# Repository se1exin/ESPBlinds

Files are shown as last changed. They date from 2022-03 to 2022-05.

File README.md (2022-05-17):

# ESPBlinds - Wifi Controlled Roller Blinds

STLs are available in the [files](files) folder in this repo, and on thingiverse at: https://www.thingiverse.com/thing:5321952

## Arduino Program
This Repo contains the Arduino program used to run the ESP-8266 controller.

The code has been tested on Arduino IDE v1.8.19 on Linux and Mac, if you have issues compiling please try using this version of the Arduino IDE.

### Constants file
**IMPORTANT: You need to create constants.h**

Copy-paste the file `constants.example.h` to `constants.h` and fill update at minimum the following variables:
 - `WIFI_SSID`
 - `WIFI_PASSWORD`
 - `MQTT_SERVER`
 - `MQTT_USER`
 - `MQTT_PASSWORD`

All MQTT topics are also defined in `constants.h`, feel free to customise these if you prefer different topic naming.

### Arduino Libraries 
Please ensure the following Arduino Libraries are installed using the Arduino Library Manager:
 - ESP8266WiFi - https://arduino-esp8266.readthedocs.io/en/latest/esp8266wifi/readme.html
 - PubSubClient -  https://www.arduino.cc/reference/en/libraries/pubsubclient/

### Compiling for ESP8266
If you are using the ESP-12F modukle as I did, use the following Board settings in Arduino IDE:
- Board: `NodeMCU 1.0 (ESP-12E)`
- Upload Speed: `115200`
- (I left all other settings as the default)

## Parts used
 - 2.8v 1.7A Stepper Driver (SY42STH38-1684A): https://www.pololu.com/product/2267
 - DRV8825 Stepper Motor Driver: https://www.pololu.com/product/2133
 - ESP8266 12-F: https://www.katranji.com/tocimages/files/423280-229082.pdf
 - 12v DC 50mm Fan: https://core-electronics.com.au/extruder-50mm-fan.html
 - 12v 2A DC Power Supply (no link - just make sure the amperage is higher than your stepper, with some room to breath to also run the ESP8266)
 - 4x8x3mm Bearings for the main gear - https://core-electronics.com.au/makeblock-plain-ball-bearing-4-8-3mm-10-pack.html
 - M3x8mm screws (x4) for mounting the motor
 - M3x4mm screws (x4) for mounting the lid
 - 4x wood screws to mount the whole thing to the wall - you will need to decide the best screws to use based on what your wall is made out of.

...and some generic electronics components, such as 3.3v regulator, capacitors, resistors, and NPN transistors.

See the schematic for full details

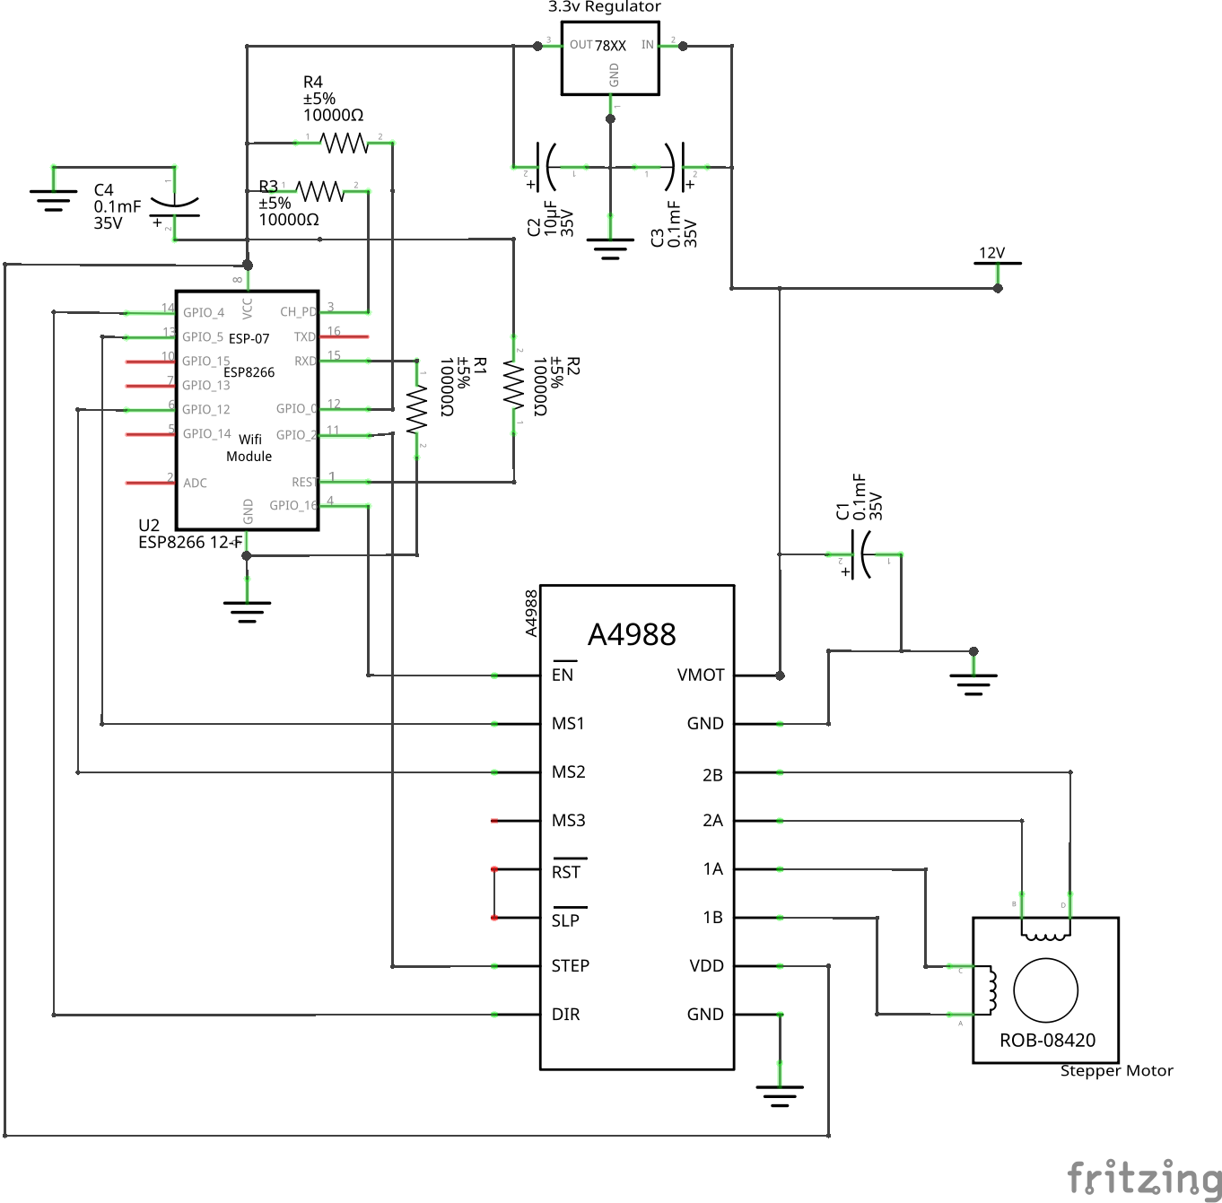
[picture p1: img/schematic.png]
Schematic


**NOTE** The schematic shows the A4988 Stepper Driver, which was from a previous iteration. I am now using the DRV8255 which has a slightly different pinout.

Most notably on the DRV8255, the VDD pin is not present and instead replaced by the FAULT pin (which I am not using), and the RST and SLP pins go to 3.3v rather than being tied to each other.

## Mounting instructions
- First mount the enclosure to the wall. The motor covers one of the screw holes.
- Mount the stepper motor before adding the main gear - it covers access to 2 of the motor screw holes
- Then put in the main gear and everything else
- Then add on the lid!

## MQTT Topics
The unit is controlled remotely via MQTT, as I use Home Assistant and the MQTT integration for all my home automation projects.

See `constants.example.h` for all the available topics - you can also change the topic stings to whatever you want.

The topics are grouped into two types: Control and Non-Control topics. Control topics have `control` somewhere in the name, and the unit listens to these topics and does something (e.g. moves the blinds) when a message is received on the topic. Non-control topics don't have the word `control` in the them, and are used to send messages out from the unit to let the world know it's current states and settings.

### Control Topics

#### `MQTT_TOPIC_CONTROL_ENABLED`
Enables/Disables the Stepper Motor Driver - useful for emergency stopping the motor

Expected Values:
 - `0` - Disable
 - `1` - Enable

#### `MQTT_TOPIC_CONTROL_DIRECTION`
Changes the direction of the stepper motor/the direction the blinds will move

Expected Values:
 - `0` - Open/Up
 - `1` - Close/Down

#### `MQTT_TOPIC_CONTROL_STEPFOR`
Immediately move the stepper motor X *full* steps, in the currently set direction (e.g. set via `MQTT_TOPIC_CONTROL_DIRECTION`).

Expected Value: An integer for the number of steps

#### `MQTT_TOPIC_CONTROL_BLINDS`
Tell the blinds to either open or close, for the set number of steps required to complete the journey (e.g. set via `MQTT_TOPIC_CONTROL_STEPS_VERTICAL`)

Expected Values:
 - `opened` - Open the blinds
 - `closed` - Close the blinds

#### `MQTT_TOPIC_CONTROL_MODE_OPEN`
Set the stepper mode used during *Opening* of Blinds (e.g. full step, half step, quarter step, etc)

**This value is saved to eeprom, so it will persist if the ESP8266 restarts or looses power**

Expected Values:
 - `1` - Full Step Mode
 - `2` - Half Step Mode
 - `4` - Quarter Step Mode
 - `8` - Eighth Step Mode

#### `MQTT_TOPIC_CONTROL_MODE_CLOSE`
Set the stepper mode used during *Closing* of Blinds (e.g. full step, half step, quarter step, etc)

**This value is saved to eeprom, so it will persist if the ESP8266 restarts or looses power**

Expected Values:
 - `1` - Full Step Mode
 - `2` - Half Step Mode
 - `4` - Quarter Step Mode
 - `8` - Eighth Step Mode

#### `MQTT_TOPIC_CONTROL_DELAY_OPEN`
Set the stepper speed used during *Opening* of Blinds. (Less speed == more torque).

**This value is saved to eeprom, so it will persist if the ESP8266 restarts or looses power**

Expected Value: An integer for the **microseconds** between steps

#### `MQTT_TOPIC_CONTROL_DELAY_CLOSE`
Set the stepper speed used during *Closing* of Blinds. (Less speed == more torque).

**This value is saved to eeprom, so it will persist if the ESP8266 restarts or looses power**

Expected Value: An integer for the **microseconds** between steps

#### `MQTT_TOPIC_CONTROL_STEPS_VERTICAL`
Set the number of steps to take when performing a full `open` or `close` cycle (See `MQTT_TOPIC_CONTROL_BLINDS`)

**This value is saved to eeprom, so it will persist if the ESP8266 restarts or looses power**

Expected Value: An integer for the number of steps to take

## Non-Control Topics

#### `MQTT_TOPIC_STATE`
Publishes the current movement state of the blinds

Expected Values:
 - `opening`
 - `opened`
 - `closing`
 - `closed`

#### `MQTT_TOPIC_STATE`
Publishes the current movement state of the blinds

Expected Values:
 - `opening`
 - `opened`
 - `closing`
 - `closed`

#### `MQTT_TOPIC_STEPS`
Publishes the current number of full steps taken (note this is only sent every 250 steps)

Expected Value: Integer

#### `MQTT_TOPIC_ENABLED`
Publishes if the stepper motor driver is currently enabled

Expected Values:
 - `0` - Not Enabled
 - `1` - Enabled

#### `MQTT_TOPIC_DIRECTION`
Publishes the current stepper motor direction

Expected Values:
 - `forwards`
 - `backwards`

#### `MQTT_TOPIC_MODE`
Publishes the current stepper motor step mode

Expected Values:
 - `1` - Full Step Mode
 - `2` - Half Step Mode
 - `4` - Quarter Step Mode
 - `8` - Eighth Step Mode

#### `MQTT_TOPIC_STATUS`
Publishes the current MQTT connection status

Expected Values:
 - `connected` - The unit is connected to MQTT
 - `disconnected` - The unit has disconnected from MQTT (this is sent as an MQTT last-will message, so it is mostly reliable)

#### `MQTT_TOPIC_MODE_OPEN`
Publishes the current step mode for the *Opening* sequence (see `MQTT_TOPIC_CONTROL_MODE_OPEN`)

Expected Values:
 - `1` - Full Step Mode
 - `2` - Half Step Mode
 - `4` - Quarter Step Mode
 - `8` - Eighth Step Mode

#### `MQTT_TOPIC_MODE_CLOSE`
Publishes the current step mode setting for the *Closing* sequence (see `MQTT_TOPIC_CONTROL_MODE_CLOSE`)

Expected Values:
 - `1` - Full Step Mode
 - `2` - Half Step Mode
 - `4` - Quarter Step Mode
 - `8` - Eighth Step Mode

#### `MQTT_TOPIC_DELAY_OPEN`
Publishes the current step speed setting for the *Opening* sequence (see `MQTT_TOPIC_CONTROL_DELAY_OPEN`)

Expected Value: Integer

#### `MQTT_TOPIC_DELAY_CLOSE`
Publishes the current step speed setting for the *Closing* sequence (see `MQTT_TOPIC_CONTROL_DELAY_CLOSE`)

Expected Value: Integer

#### `MQTT_TOPIC_STEPS_VERTICAL`
Publishes the setting for the current number of full steps to take when performing a full `open` or `close` cycle (see `MQTT_TOPIC_CONTROL_STEPS_VERTICAL`)

Expected Value: Integer

## Some more pics

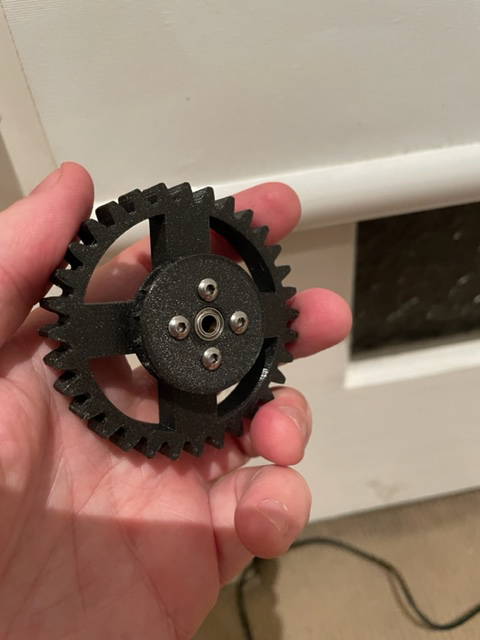
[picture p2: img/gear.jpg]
Gear


Main gear with ball-chain gear attachment

---

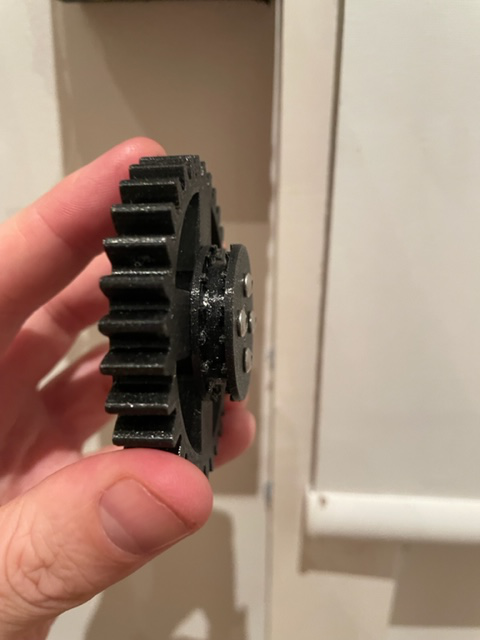
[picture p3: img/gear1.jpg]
Ball-Chain attachment


Ball-chain gear attachment (another angle)

---

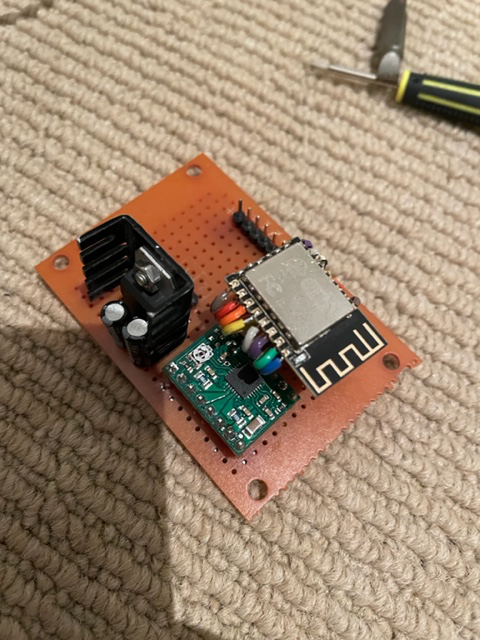
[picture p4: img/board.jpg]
Control Board


Control Board (with A4988 instead of DRV8255 stepper driver)

---

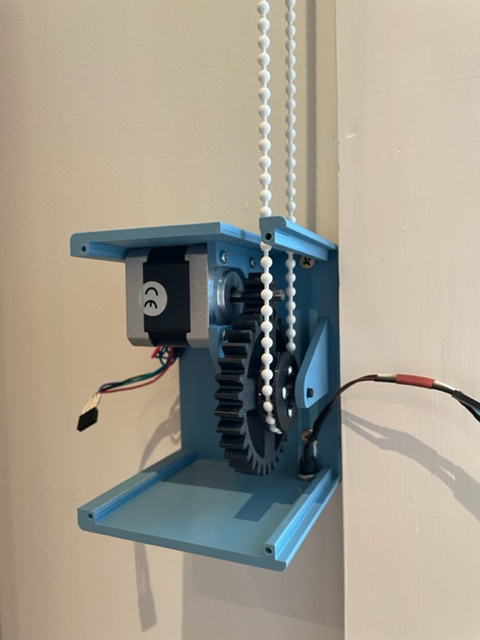
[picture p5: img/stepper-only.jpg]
Housing with stepper


Housing with stepper motor and gear installed

---

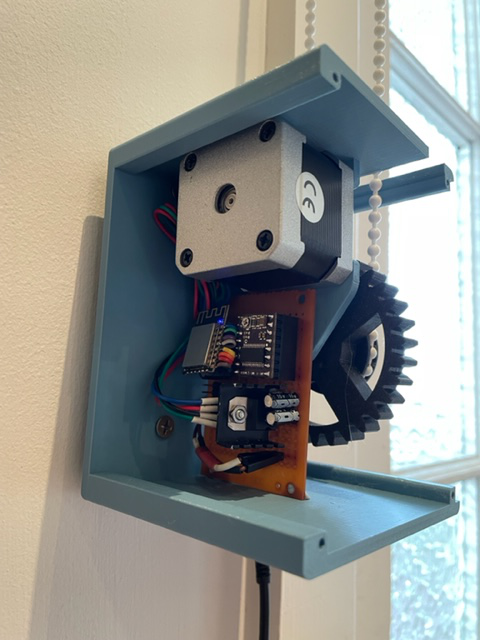
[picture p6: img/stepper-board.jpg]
Housing with stepper and board


Housing with stepper motorm, gears, and board installed

---

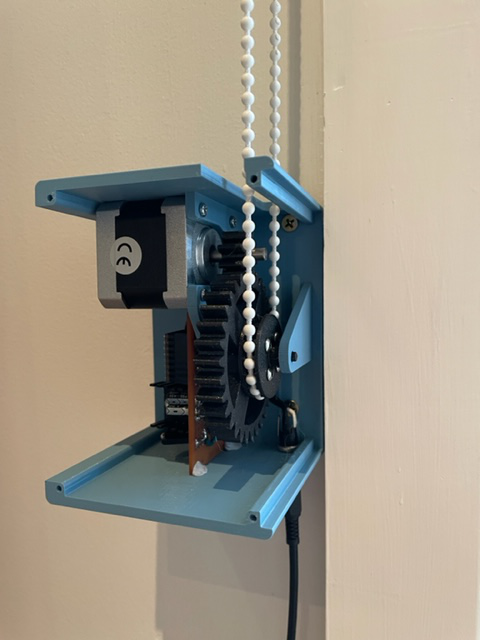
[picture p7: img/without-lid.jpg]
Housing with stepper and board


Everything ready to go, just need to put the lid on

## License
MIT - see [LICENSE.md](https://github.com/se1exin/ESPBlinds/blob/master/LICENSE.md)

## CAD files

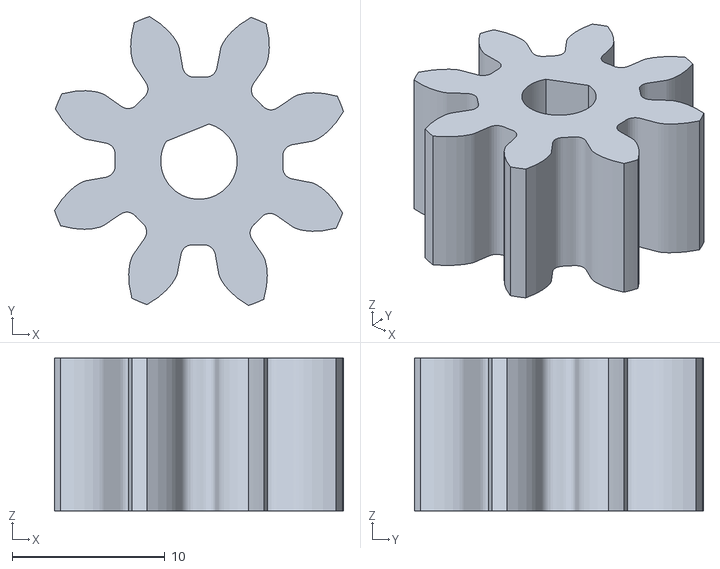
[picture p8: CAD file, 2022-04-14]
files/Auto_Blinds_small_gear.stl
18.9 x 18.9 x 10.0

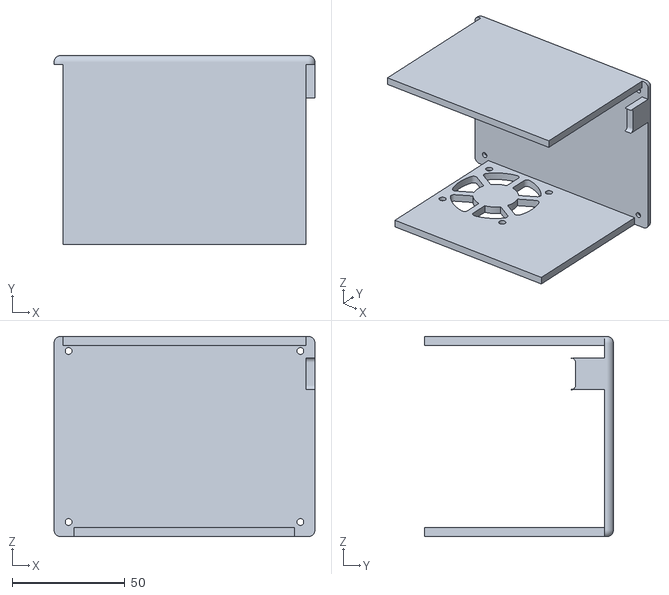
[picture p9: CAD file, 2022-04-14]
files/Auto_Blinds_Lid.stl
116.0 x 84.0 x 89.0

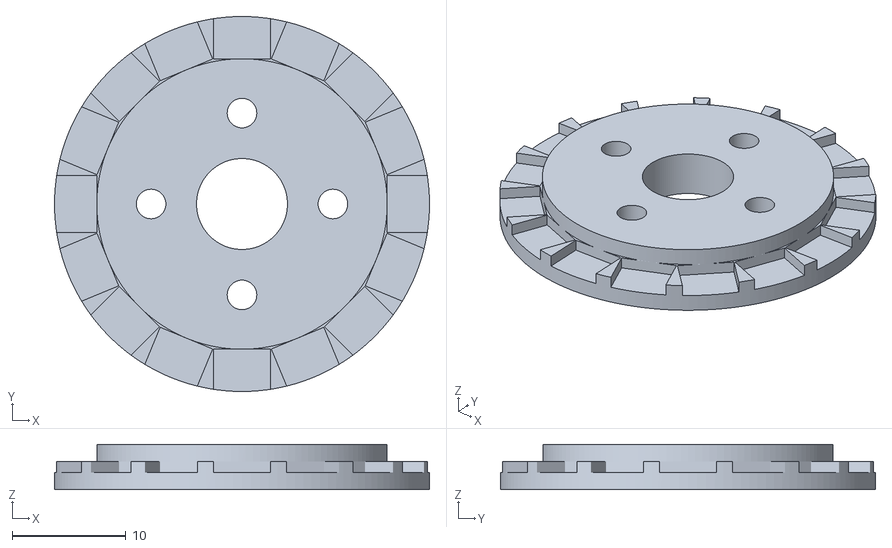
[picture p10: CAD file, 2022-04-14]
files/Auto_Blinds_chain_gear_bottom.stl
33.0 x 33.0 x 4.00

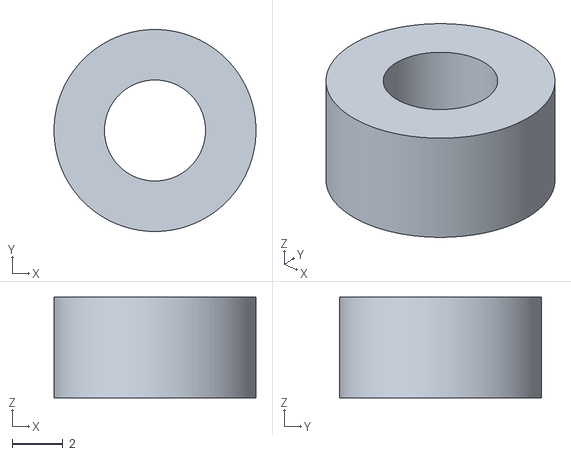
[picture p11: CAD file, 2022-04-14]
files/Auto_Blinds_gear_spacer.stl
8.00 x 8.00 x 4.00

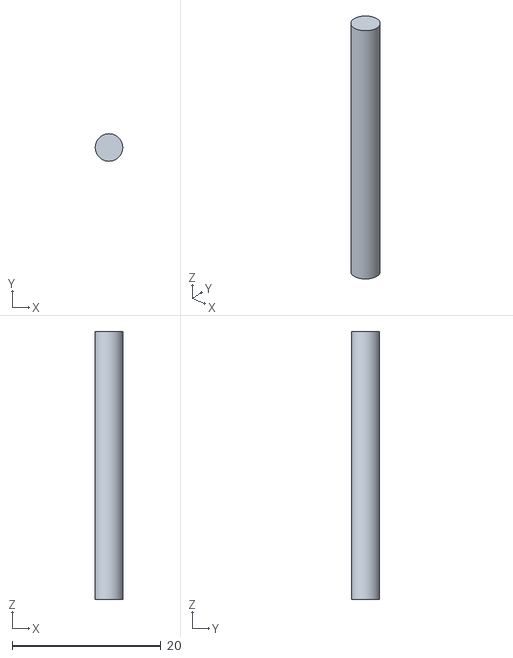
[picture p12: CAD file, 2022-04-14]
files/Auto_Blinds_shaft.stl
3.70 x 3.70 x 36.0

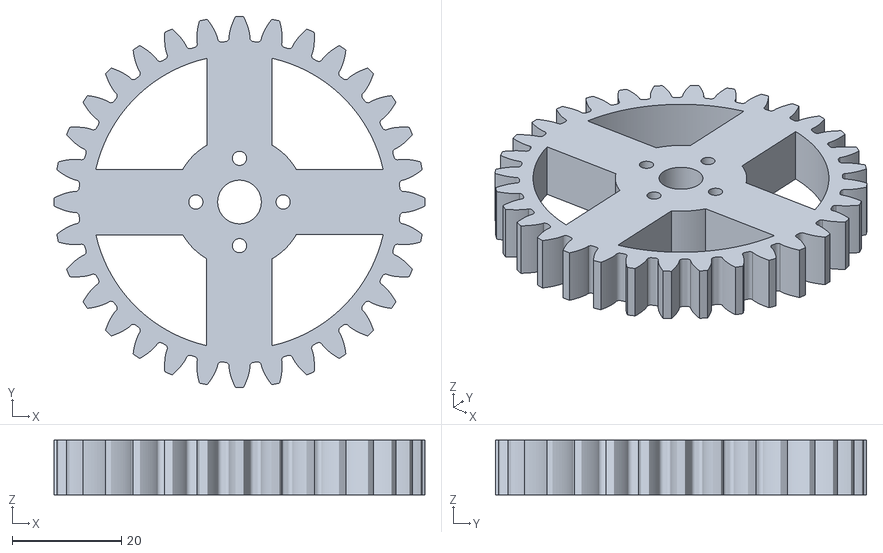
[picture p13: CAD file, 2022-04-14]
files/Auto_Blinds_big_gear.stl
68.0 x 68.0 x 10.0

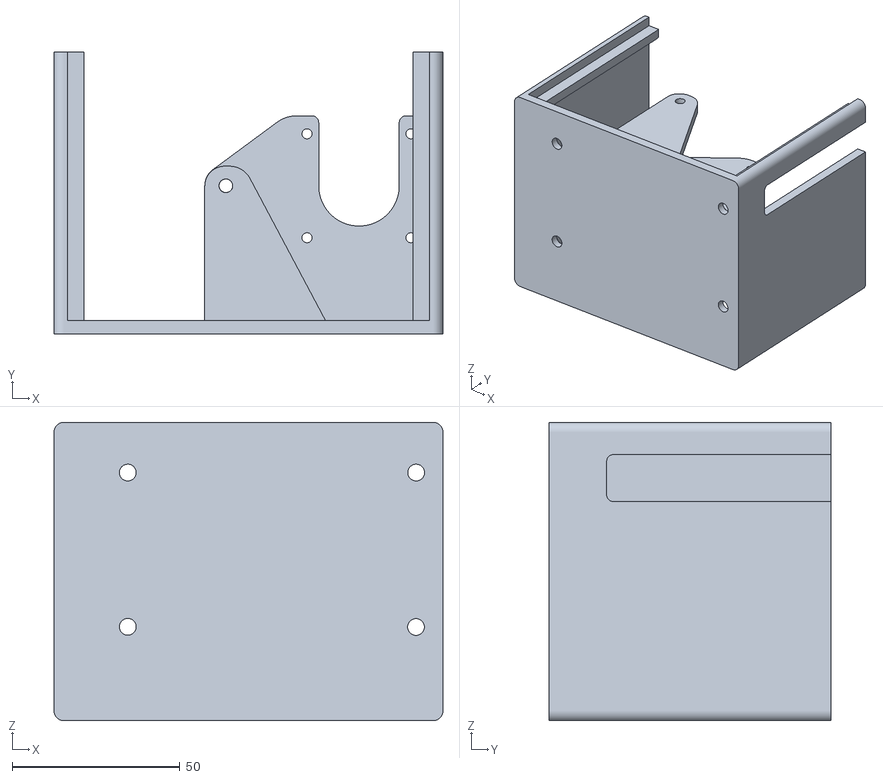
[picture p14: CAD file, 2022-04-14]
files/Auto_Blinds_Case.stl
116.0 x 84.0 x 89.0

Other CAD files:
files/Auto_Blinds_chain_gear_top.stl

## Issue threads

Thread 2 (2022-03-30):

Thingiverse link is currently broken.

lwoollett, 2022-03-30:
Hi, currently the thingiverse link provided in the readme is broken.
Would it be possible to get the objects included in the git repo as well for redundancy?

Closed 2022-03-31.

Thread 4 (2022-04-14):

Compiling errors

LapisTomato, 2022-04-14:
These are the errors I am getting:

Arduino: 1.8.20 Hourly Build 2021/12/20 07:33 (Windows 10), Board: "Generic ESP8266 Module, 80 MHz, Flash, Disabled (new aborts on oom), Disabled, All SSL ciphers (most compatible), 32KB cache + 32KB IRAM (balanced), Use pgm_read macros for IRAM/PROGMEM, dtr (aka nodemcu), 26 MHz, 40MHz, DOUT (compatible), 1MB (FS:64KB OTA:~470KB), 2, nonos-sdk 2.2.1+100 (190703), v2 Lower Memory, Disabled, None, Only Sketch, 115200"
C:\*\*\ESPBlinds-master\ESPBlinds-master\sketch_apr11a\ESPBlinds.ino: In function 'void mqttReconnect()':
ESPBlinds:282:119: error: no matching function for call to 'PubSubClient::connect(const char [18], const char*&, const char*&, const char [30], int, bool, const char [13], bool)'
282 |     if (mqttClient.connect(MQTT_CLIENT_ID, MQTT_USER, MQTT_PASSWORD, MQTT_TOPIC_STATUS, 1, true, "disconnected", false)) {
|                                                                                                                       ^
In file included from C:\*\*\ESPBlinds-master\ESPBlinds-master\sketch_apr11a\ESPBlinds.ino:3:
C:\Users\*\*\Documents\Arduino\libraries\ESP8266_Microgear/PubSubClient.h:119:12: note: candidate: 'virtual boolean PubSubClient::connect(const char*)'
119 |    boolean connect(const char* id);
|            ^~~~~~~
C:\Users\*\*\Documents\Arduino\libraries\ESP8266_Microgear/PubSubClient.h:119:12: note:   candidate expects 1 argument, 8 provided
C:\Users\*\*\Documents\Arduino\libraries\ESP8266_Microgear/PubSubClient.h:120:12: note: candidate: 'virtual boolean PubSubClient::connect(const char*, const char*, const char*)'
120 |    boolean connect(const char* id, const char* user, const char* pass);
|            ^~~~~~~
C:\Users\*\*\Documents\Arduino\libraries\ESP8266_Microgear/PubSubClient.h:120:12: note:   candidate expects 3 arguments, 8 provided
C:\Users\*\*\Documents\Arduino\libraries\ESP8266_Microgear/PubSubClient.h:121:12: note: candidate: 'virtual boolean PubSubClient::connect(const char*, const char*, uint8_t, boolean, const char*)'
121 |    boolean connect(const char* id, const char* willTopic, uint8_t willQos, boolean willRetain, const char* willMessage);
|            ^~~~~~~
C:\Users\*\*\Documents\Arduino\libraries\ESP8266_Microgear/PubSubClient.h:121:12: note:   candidate expects 5 arguments, 8 provided
C:\Users\*\*\Documents\Arduino\libraries\ESP8266_Microgear/PubSubClient.h:122:12: note: candidate: 'virtual boolean PubSubClient::connect(const char*, const char*, const char*, const char*, uint8_t, boolean, const char*)'
122 |    boolean connect(const char* id, const char* user, const char* pass, const char* willTopic, uint8_t willQos, boolean willRetain, const char* willMessage);
|            ^~~~~~~
C:\Users\*\OneDrive\Documents\Arduino\libraries\ESP8266_Microgear/PubSubClient.h:122:12: note:   candidate expects 7 arguments, 8 provided
exit status 1
no matching function for call to 'PubSubClient::connect(const char [18], const char*&, const char*&, const char [30], int, bool, const char [13], bool)'
This report would have more information with
"Show verbose output during compilation"
option enabled in File -> Preferences.

se1exin, 2022-04-14:
@LapisTomato did you install the required Arduino libraries via the Arduino Library Manager?
 - ESP8266WiFi - https://arduino-esp8266.readthedocs.io/en/latest/esp8266wifi/readme.html
 - PubSubClient - https://www.arduino.cc/reference/en/libraries/pubsubclient/

LapisTomato, 2022-04-14:
@se1exin Yes I did.

se1exin, 2022-04-15:
Oh I've missed documented the ESP8266 library, it needs to be installed via Arduino Board Manager.

Here's the first google result I found on how to install it: https://randomnerdtutorials.com/how-to-install-esp8266-board-arduino-ide/

LapisTomato, 2022-04-15:
@se1exin I already had that installed. Should have sent that picture, sorry.

Closed 2022-04-29.

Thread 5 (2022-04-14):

Hardware issue

LapisTomato, 2022-04-14:
I followed the diagram and wired everything twice but the esp8266 doesn't seem to be turning on. It turns on when connected to my laptop. I know you can't know the problem without seeing the circuit physically so what are the general issues with it?

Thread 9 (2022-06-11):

Thank you!

apanteleev, 2022-06-11:
Hi,
I just wanted to say thanks for publishing these project files. I'm relatively new to the 3D printing and Arduino world, and I used this project to learn how to build a similar device myself, with some improvements. You can find my result at https://github.com/apanteleev/autoblinds and reuse any ideas if you want to.

se1exin, 2022-06-15:
Hi @apanteleev, thanks for dropping in and saying hi!

I just had a look at your project - I really like the improvements you have made! I might incorporate some of them back into mine if I get some spare time. I especially like that you've added push buttons to control it locally.

Keep up the good work!

Closed 2022-06-16.

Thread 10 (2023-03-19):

MQTT & homeassistant

friendlyFriend4000, 2023-03-19:
I am sort of lost in terms on how to control my blinds motor. I have successfully setup a wifi connection between my esp8266 and MQTT connection also reports as successfull (at that's what the console reports). Now how do I actually operate the motor? I dont see esp8266 on my homeassistant dashboard.

se1exin, 2023-04-05:
Hi there, if you've used the code from this repo to flash the ESP8266 you will need to manually add each MQTT topic to the Home Assistant config.

Here's my config for HA:
```
mqtt:
  sensor:
    - name: "Bedroom Blinds: Status"
      unique_id: "esp8266_blinds_01_status"
      object_id: "esp8266_blinds_01_status"
      state_topic: "home/esp8266_blinds_01/status"
    - name: "Bedroom Blinds: Current Mode"
      unique_id: "esp8266_blinds_01_mode"
      object_id: "esp8266_blinds_01_mode"
      state_topic: "home/esp8266_blinds_01/mode"
    - name: "Bedroom Blinds: Enabled"
      unique_id: "esp8266_blinds_01_enabled"
      object_id: "esp8266_blinds_01_enabled"
      state_topic: "home/esp8266_blinds_01/enabled"
    - name: "Bedroom Blinds: State"
      unique_id: "esp8266_blinds_01_state"
      object_id: "esp8266_blinds_01_state"
      state_topic: "home/esp8266_blinds_01/state"
    - name: "Bedroom Blinds: Current Steps"
      unique_id: "esp8266_blinds_01_steps"
      object_id: "esp8266_blinds_01_steps"
      state_topic: "home/esp8266_blinds_01/steps"
    - name: "Bedroom Blinds: Direction"
      unique_id: "esp8266_blinds_01_direction"
      object_id: "esp8266_blinds_01_direction"
      state_topic: "home/esp8266_blinds_01/direction"
    - name: "Bedroom Blinds: Vertical Steps"
      unique_id: "esp8266_blinds_01_steps_vertical"
      object_id: "esp8266_blinds_01_steps_vertical"
      state_topic: "home/esp8266_blinds_01/steps/vertical"
    - name: "Bedroom Blinds: Open Mode"
      unique_id: "esp8266_blinds_01_mode_open"
      object_id: "esp8266_blinds_01_mode_open"
      state_topic: "home/esp8266_blinds_01/mode/open"
    - name: "Bedroom Blinds: Close Mode"
      unique_id: "esp8266_blinds_01_mode_close"
      object_id: "esp8266_blinds_01_mode_close"
      state_topic: "home/esp8266_blinds_01/mode/close"
    - name: "Bedroom Blinds: Open Delay"
      unique_id: "esp8266_blinds_01_delay_open"
      object_id: "esp8266_blinds_01_delay_open"
      state_topic: "home/esp8266_blinds_01/delay/open"
    - name: "Bedroom Blinds: Close Delay"
      unique_id: "esp8266_blinds_01_delay_close"
      unique_id: "esp8266_blinds_01_delay_close"
      state_topic: "home/esp8266_blinds_01/delay/close"

  switch:
    - name: "Bedroom Blinds: Enabled"
      unique_id: "esp8266_blinds_01_enabled_switch"
      object_id: "esp8266_blinds_01_enabled_switch"
      state_topic: "home/esp8266_blinds_01/enabled"
      command_topic: "home/esp8266_blinds_01/control/enabled"
      availability_topic: "home/esp8266_blinds_01/status"
      payload_available: "connected"
      payload_not_available: "disconnected"
      qos: 1
      payload_on: 1
      payload_off: 0
    - name: "Bedroom Blinds: Opened"
      unique_id: "esp8266_blinds_01_open_switch"
      object_id: "esp8266_blinds_01_open_switch"
      state_topic: "home/esp8266_blinds_01/state"
      command_topic: "home/esp8266_blinds_01/control/blinds"
      availability_topic: "home/esp8266_blinds_01/status"
      payload_available: "connected"
      payload_not_available: "disconnected"
      qos: 1
      payload_on: "opened"
      payload_off: "closed"
```

Closed 2023-09-23.

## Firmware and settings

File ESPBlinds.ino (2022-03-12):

#include <ESP8266WiFi.h>
#include <EEPROM.h>
#include <PubSubClient.h>
#include "constants.h"
#include "EasyDriver.h"

// Outputs
const int PIN_STEP = 4;
const int PIN_DIR = 5;
const int PIN_MS1 = -1;
const int PIN_MS2 = -1;
const int PIN_ENABLE = 14;
const int PIN_FAN = 13;

// Inputs
//const int PIN_CUTOFF_CLOSE = 0;
//const int PIN_CUTOFF_OPEN = 3;

EasyDriver stepper = EasyDriver(PIN_STEP, PIN_DIR, PIN_MS1, PIN_MS2, PIN_ENABLE);

WiFiClient espClient;
PubSubClient mqttClient(espClient);

// Down = forwards == close
// Up   = Reverse == open
const int DIRECTION_CLOSE = EASYDRIVER_DIRECTION_FORWARDS;
const int DIRECTION_OPEN = EASYDRIVER_DIRECTION_REVERSE;

const bool MQTT_SEND_STEPS = false;

// Vars that are updatable via MQTT and saved into EEPROM...

// If this number is not found in EEPROM, then we assume no EEPROM values exist/have been saved
// and all other EEPROM values should be discarded/fallback to default values.
// See loadFromEeprom()
int EEPROM_MAGIC_NUMBER = 10001;
int STEPS_VERTICAL = 15000; // Number of full steps required to complete open/close sequence

int DELAY_CLOSE = 500; // In micros
int MODE_CLOSE = EASYDRIVER_MODE_FULL_STEP;

int DELAY_OPEN = 500; // In micros
int MODE_OPEN = EASYDRIVER_MODE_FULL_STEP;

// Locals
int currentStep = 0;
int currentMode = MODE_OPEN;
int stepDirection = EASYDRIVER_DIRECTION_FORWARDS;
bool stepperEnabled = true;
bool isOpening = false;
bool isClosing = false;

void setup() {
  // Cut off switches (not used in hardware, but implemented in case required in future)
//  pinMode(PIN_CUTOFF_CLOSE, INPUT_PULLUP);
//  pinMode(PIN_CUTOFF_OPEN, INPUT_PULLUP);
  pinMode(PIN_FAN, OUTPUT);

  stepper.reset();

  Serial.begin(115200);
  while (! Serial);

  setupWifi();
  mqttClient.setServer(MQTT_SERVER, 1883);
  mqttClient.setCallback(mqttCallback);
  if (!mqttClient.connected()) {
    mqttReconnect();
  }

  mqttPublish(MQTT_TOPIC_ENABLED, 0);
  mqttPublish(MQTT_TOPIC_STATE, "closed");
  mqttPublish(MQTT_TOPIC_STEPS, currentStep);
  loadFromEeprom();

  // Topic for controlling the stepper remotely
  mqttClient.subscribe(MQTT_TOPIC_CONTROL_ENABLED);
  mqttClient.subscribe(MQTT_TOPIC_CONTROL_DIRECTION);
  mqttClient.subscribe(MQTT_TOPIC_CONTROL_STEPFOR);
  mqttClient.subscribe(MQTT_TOPIC_CONTROL_BLINDS);

  // Topics for updating EEPROM values remotely
  mqttClient.subscribe(MQTT_TOPIC_CONTROL_MODE_OPEN);
  mqttClient.subscribe(MQTT_TOPIC_CONTROL_MODE_CLOSE);
  mqttClient.subscribe(MQTT_TOPIC_CONTROL_DELAY_OPEN);
  mqttClient.subscribe(MQTT_TOPIC_CONTROL_DELAY_CLOSE);
  mqttClient.subscribe(MQTT_TOPIC_CONTROL_STEPS_VERTICAL);
}


/**
 * MAIN LOOP
 */
void loop() {
  if (!mqttClient.connected()) {
    mqttReconnect();
  }
  mqttClient.loop();
}


void closeBlinds() {
  isClosing = true;
  mqttPublish(MQTT_TOPIC_STATE, "closing");
  setStepperDirection(DIRECTION_CLOSE);
  setStepperMode(MODE_CLOSE);
  stepFor(STEPS_VERTICAL);
  mqttPublish(MQTT_TOPIC_STATE, "closed");
  isClosing = false;
}

void openBlinds() {
  isOpening = true;
  mqttPublish(MQTT_TOPIC_STATE, "opening");
  setStepperDirection(DIRECTION_OPEN);
  setStepperMode(MODE_OPEN);
  stepFor(STEPS_VERTICAL); 
  mqttPublish(MQTT_TOPIC_STATE, "opened");
  isOpening = false;
}


/**
 * STEPPER WRAPPERS
 */
void stepFor(int steps) {
  setStepperEnabled(true);
  for (int i = 0; i < steps; i++) {
//    Serial.print("STEP");
//    Serial.println(i);
    // Stepping mode is effectively a multiplier on the desired number of steps
    // E.g. a quarter step mode, to achieve a full step we need to do 4x stepper steps
    for (int x = 0; x < currentMode; x++) {
      stepper.step();
    }

    currentStep += stepDirection;
//    if (stepDirection == DIRECTION_CLOSE && digitalRead(PIN_CUTOFF_CLOSE) == LOW) {
//      Serial.println("ABORT CLOSE");
//      break;
//    }
//    if (stepDirection == DIRECTION_OPEN && digitalRead(PIN_CUTOFF_OPEN) == LOW) {
//      Serial.println("ABORT OPEN");
//      break;
//    }
    if (!stepperEnabled) {
      break;
    }
    
    if (MQTT_SEND_STEPS) {
      if (currentStep % 250 == 0) {
        mqttPublish(MQTT_TOPIC_STEPS, currentStep);
      }
    }
    mqttClient.loop();
  }
  setStepperEnabled(false);
}

void setStepperMode(int mode) {
  stepper.setMode(mode);
  currentMode = mode;
  mqttPublish(MQTT_TOPIC_MODE, mode);
}

void setStepperEnabled(bool enabled) {
  stepper.enable(enabled);
  
  if (enabled) {
    digitalWrite(PIN_FAN, HIGH);
    mqttPublish(MQTT_TOPIC_ENABLED, 1); 
  } else {
    digitalWrite(PIN_FAN, LOW);
    mqttPublish(MQTT_TOPIC_ENABLED, 0); 
  }
  stepperEnabled = enabled;
}

void setStepperDirection(int direction) {
  stepper.setDirection(direction);
  stepDirection = direction;
  if (direction == EASYDRIVER_DIRECTION_FORWARDS) {
    stepper.setDelay(DELAY_CLOSE);
    mqttPublish(MQTT_TOPIC_DIRECTION, "forwards");
  } else {
    stepper.setDelay(DELAY_OPEN);
    mqttPublish(MQTT_TOPIC_DIRECTION, "reverse");
  }
}


/**
 * WIFI / MQTT HELPERS
 */
void setupWifi() {
  Serial.print("Connecting to ");
  Serial.println(WIFI_SSID);

  WiFi.begin(WIFI_SSID, WIFI_PASSWORD);

  while (WiFi.status() != WL_CONNECTED) {
    delay(500);
    Serial.print(".");
  }

  Serial.println();
  Serial.println("WiFi connected");
  Serial.print("IP address: ");
  Serial.println(WiFi.localIP());
}


void mqttCallback(char* topic, byte* payload, unsigned int length) {
  String topicStr = topic;
  String value = "";
  for (int i = 0; i < length; i++) {
      value += (char)payload[i];
  }

  Serial.println("mqttCallback !");
  Serial.println(topicStr);
  Serial.println(value);

  if (topicStr == MQTT_TOPIC_CONTROL_ENABLED) {
    if (value.equals("1")) {
      setStepperEnabled(true);
    } else if (value.equals("0")) {
      setStepperEnabled(false);
    }
  }

  if (topicStr == MQTT_TOPIC_CONTROL_DIRECTION) {
    if (value.equals("1")) {
      setStepperDirection(DIRECTION_CLOSE);
    } else if (value.equals("0")) {
      setStepperDirection(DIRECTION_OPEN);
    }
  }

  if (topicStr == MQTT_TOPIC_CONTROL_STEPFOR) {
    int steps = value.toInt();
    stepFor(steps);
  }

  if (topicStr == MQTT_TOPIC_CONTROL_BLINDS) {
    if (value.equals("opened") && !isOpening) {
    // if (value.equals("opened")) {
      openBlinds();
    } else if (value.equals("closed") && !isClosing) {
    // } else if (value.equals("closed")) {
      closeBlinds();
    }
  }

  if (topicStr == MQTT_TOPIC_CONTROL_MODE_OPEN) {
    MODE_OPEN = value.toInt();
    saveToEeprom();
  }
  if (topicStr == MQTT_TOPIC_CONTROL_MODE_CLOSE) {
    MODE_CLOSE = value.toInt();
    saveToEeprom();
  }
  if (topicStr == MQTT_TOPIC_CONTROL_DELAY_OPEN) {
    DELAY_OPEN = value.toInt();
    saveToEeprom();
  }
  if (topicStr == MQTT_TOPIC_CONTROL_DELAY_CLOSE) {
    DELAY_CLOSE = value.toInt();
    saveToEeprom();
  }
  if (topicStr == MQTT_TOPIC_CONTROL_STEPS_VERTICAL) {
    STEPS_VERTICAL = value.toInt();
    saveToEeprom();
  }
}

void mqttReconnect() {
  while (!mqttClient.connected()) {
    Serial.print("Attempting MQTT connection...");

    // Attempt to connect
    if (mqttClient.connect(MQTT_CLIENT_ID, MQTT_USER, MQTT_PASSWORD, MQTT_TOPIC_STATUS, 1, true, "disconnected", false)) {
      Serial.println("connected");

      // Once connected, publish an announcement...
      mqttClient.publish(MQTT_TOPIC_STATUS, "connected", true);
    } else {
      Serial.print("failed, rc=");
      Serial.print(mqttClient.state());
      Serial.println(" try again in 5 seconds");
      delay(5000);
    }
  }
}

void mqttPublish(char *topic, int payload) {
  // Serial.print(topic);
  // Serial.print(": ");
  // Serial.println(payload);

  mqttClient.publish(topic, String(payload).c_str(), true);
}

void mqttPublish(char *topic, String payload) {
  // Serial.print(topic);
  // Serial.print(": ");
  // Serial.println(payload);

  mqttClient.publish(topic, payload.c_str(), true);
}


/**
 * EEPROM HELPERS
 */

void loadFromEeprom() {
  EEPROM.begin(24);

  //Read data from eeprom
  int magicNumber;
  int modeOpen;
  int modeClose;
  int delayOpen;
  int delayClose;
  int stepsVertical;

  EEPROM.get(0, modeOpen);
  EEPROM.get(4, modeClose);
  EEPROM.get(8, delayOpen);
  EEPROM.get(12, delayClose);
  EEPROM.get(16, stepsVertical);
  EEPROM.get(20, magicNumber);
  EEPROM.end();

  if (magicNumber == EEPROM_MAGIC_NUMBER) {
    Serial.print("Successfully loaded config from eeprom");
    MODE_OPEN = modeOpen;
    MODE_CLOSE = modeClose;
    DELAY_OPEN = delayOpen;
    DELAY_CLOSE = delayClose;
    STEPS_VERTICAL = stepsVertical;
  } else {
    Serial.print("EEPROM MAGIC NUMBER INCORRECT: ");
    Serial.print(magicNumber);
    Serial.print(" != ");
    Serial.println(EEPROM_MAGIC_NUMBER);
    Serial.print("Keeping default step config!");
  }

  mqttPublish(MQTT_TOPIC_MODE_OPEN, MODE_OPEN);
  mqttPublish(MQTT_TOPIC_MODE_CLOSE, MODE_CLOSE);
  mqttPublish(MQTT_TOPIC_DELAY_OPEN, DELAY_OPEN);
  mqttPublish(MQTT_TOPIC_DELAY_CLOSE, DELAY_CLOSE);
  mqttPublish(MQTT_TOPIC_STEPS_VERTICAL, STEPS_VERTICAL);
}

void saveToEeprom() {
  EEPROM.begin(24);

  EEPROM.put(0, MODE_OPEN);
  EEPROM.put(4, MODE_CLOSE);
  EEPROM.put(8, DELAY_OPEN);
  EEPROM.put(12, DELAY_CLOSE);
  EEPROM.put(16, STEPS_VERTICAL);
  EEPROM.put(20, EEPROM_MAGIC_NUMBER);
  EEPROM.commit();
  EEPROM.end();

  mqttPublish(MQTT_TOPIC_MODE_OPEN, MODE_OPEN);
  mqttPublish(MQTT_TOPIC_MODE_CLOSE, MODE_CLOSE);
  mqttPublish(MQTT_TOPIC_DELAY_OPEN, DELAY_OPEN);
  mqttPublish(MQTT_TOPIC_DELAY_CLOSE, DELAY_CLOSE);
  mqttPublish(MQTT_TOPIC_STEPS_VERTICAL, STEPS_VERTICAL);
}

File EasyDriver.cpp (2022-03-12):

//
// Created by selexin on 26/3/20.
//

#include "Arduino.h"
#include "EasyDriver.h"

EasyDriver::EasyDriver(int pinStep, int pinDir, int pinMs1, int pinMs2, int pinEnable) {
  PIN_STEP = pinStep;
  PIN_DIR = pinDir;
  PIN_MS1 = pinMs1;
  PIN_MS2 = pinMs2;
  PIN_ENABLE = pinEnable;

  pinMode(PIN_STEP, OUTPUT);
  pinMode(PIN_DIR, OUTPUT);
  pinMode(PIN_MS1, OUTPUT);
  pinMode(PIN_MS2, OUTPUT);
  pinMode(PIN_ENABLE, OUTPUT);

  enabled = false;
  currentMode = EASYDRIVER_MODE_FULL_STEP;
  direction = EASYDRIVER_DIRECTION_FORWARDS;
  delayMillis = 1000;
}

// Reset Easy Driver pins to default states
void EasyDriver::reset() {
  digitalWrite(PIN_STEP, LOW);
  digitalWrite(PIN_DIR, LOW);
  digitalWrite(PIN_MS1, LOW);
  digitalWrite(PIN_MS2, LOW);
  enable(false);
  setDelay(1000);
}


void EasyDriver::enable(bool enabled) {
  if (enabled) {
    digitalWrite(PIN_ENABLE, LOW);
  } else {
    digitalWrite(PIN_ENABLE, HIGH);
  }
  this->enabled = enabled;
}

void EasyDriver::setMode(int mode) {
  /** Table of Truth
    MS1  MS2  Microstep Resolution
    -----------------------------
    LOW  LOW  Full Step (2 Phase)
    HIGH LOW  Half Step
    LOW  HIGH Quarter Step
    HIGH HIGH Eigth Step
  */

  if (this->currentMode == mode) {
    return;
  }

  switch (mode) {
    case EASYDRIVER_MODE_EIGHTH_STEP:
      digitalWrite(PIN_MS1, HIGH);
      digitalWrite(PIN_MS2, HIGH);
      break;
    case EASYDRIVER_MODE_QUARTER_STEP:
      digitalWrite(PIN_MS1, LOW);
      digitalWrite(PIN_MS2, HIGH);
      break;
    case EASYDRIVER_MODE_HALF_STEP:
      digitalWrite(PIN_MS1, HIGH);
      digitalWrite(PIN_MS2, LOW);
      break;
    default: // (EASYDRIVER_MODE_FULL_STEP)
      digitalWrite(PIN_MS1, LOW);
      digitalWrite(PIN_MS2, LOW);
      break;
  }
  this->currentMode = mode;
}


void EasyDriver::setDirection(int direction) {
  if (this->direction == direction) {
    return;
  }
  if (direction == EASYDRIVER_DIRECTION_FORWARDS) {
    digitalWrite(PIN_DIR, LOW);
  } else if (direction == EASYDRIVER_DIRECTION_REVERSE) {
    digitalWrite(PIN_DIR, HIGH);
  }

  this->direction = direction;
}

void EasyDriver::setDelay(int millis) {
  this->delayMillis = millis;
}

void EasyDriver::step() {
  digitalWrite(PIN_STEP, HIGH);
  delayMicroseconds(delayMillis);
  digitalWrite(PIN_STEP, LOW);
  delayMicroseconds(delayMillis);
}

void EasyDriver::stepForward() {
  this->setDirection(EASYDRIVER_DIRECTION_FORWARDS);
  step();
}

void EasyDriver::stepReverse() {
  this->setDirection(EASYDRIVER_DIRECTION_REVERSE);
  step();
}

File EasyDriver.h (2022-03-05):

//
// Created by selexin on 26/3/20.
//

#ifndef STEPPER_CONTROL2_EASYDRIVER_H
#define STEPPER_CONTROL2_EASYDRIVER_H

#define EASYDRIVER_MODE_FULL_STEP    1
#define EASYDRIVER_MODE_HALF_STEP    2
#define EASYDRIVER_MODE_QUARTER_STEP 4
#define EASYDRIVER_MODE_EIGHTH_STEP  8

#define EASYDRIVER_DIRECTION_FORWARDS  1
#define EASYDRIVER_DIRECTION_REVERSE  -1

class EasyDriver {
private:
    int PIN_STEP;
    int PIN_DIR;
    int PIN_MS1;
    int PIN_MS2;
    int PIN_ENABLE;

    bool enabled;
    int currentMode;
    int direction;
    int delayMillis;

public:
    /**
     * Constructor, args:
     * PIN_STEP
     * PIN_DIR
     * PIN_MS1
     * PIN_MS2
     * PIN_ENABLE
     */
    EasyDriver(int pinStep, int pinDir, int pinMs1, int pinMs2, int pinEnable);

    // Reset all pins to defaults
    void reset();

    // Enable/disable the stepper
    void enable(bool enabled);

    // Set the resolution to one of the MODE_X_STEP constants
    void setMode(int mode);

    void setDirection(int direction);

    void setDelay(int millis);

    // Take one step in the current set direction
    void step();

    // Take one step forward
    void stepForward();

    // Take one step backwards
    void stepReverse();
};


#endif //STEPPER_CONTROL2_EASYDRIVER_H

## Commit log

2022-03-10 Fix incorrect control topics
    [ESPBlinds.ino]
2022-03-12 Change to higher power stepper motor - only use full step mode. Add support for fan to cool DRP8255 stepper driver instead of using pins for MS1 and MS2
2022-03-31 Add STLs and Arduino IDE instructions
    [Auto_Blinds_Case.stl, Auto_Blinds_Lid.stl, Auto_Blinds_big_gear.stl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]
2022-03-31 Rename stl folder to files
    [Auto_Blinds_Case.stl, Auto_Blinds_Lid.stl, Auto_Blinds_big_gear.stl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]
2022-04-14 Update constants.example.h to fix bad NULL comment
    [constants.example.h]
